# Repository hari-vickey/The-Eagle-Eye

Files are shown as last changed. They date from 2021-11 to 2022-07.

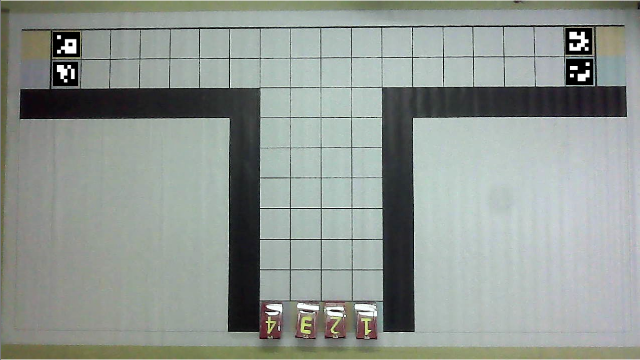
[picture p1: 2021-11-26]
test_programs/images/test.png

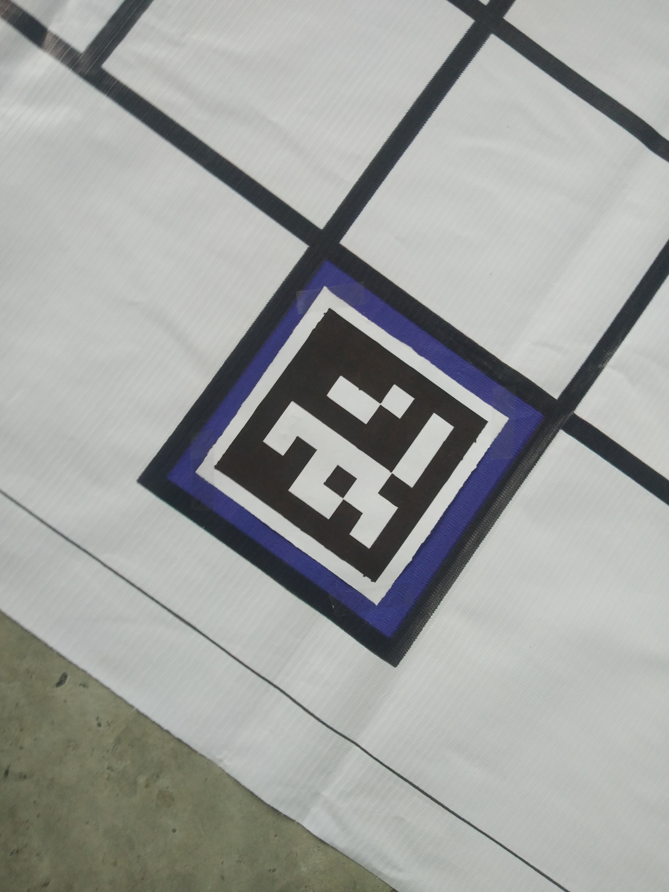
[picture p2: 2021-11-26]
test_programs/images/t.jpg

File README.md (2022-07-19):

# Flipkart GRiD 3.0

<p align="justify">
The Flipkart GRiD 3.0 Robotics Challenge is all set to test the students on their technical, analytical, and ideation skills before they present their unique solutions to the panel of domain experts at Flipkart. The Flipkart GRiD 3.0 Robotics Challenge will assess your skills in the field of analytics and robotics.
</p>

## Problem Statement

<p align="justify">
Behind the scenes in the e-commerce industry lies a sophisticated system of automation and robotics to help bring down costs and deliver goods to customers at the fastest speeds possible. Flipkart's current upcoming facility - expected to be one of the largest in Asia, has a throughput of over 40,000 units/hour. They are constantly looking for ways to increase our scale and speed while trying to minimize cost.
</p>

1. A central monitoring/navigation system (such as a camera or multiple cameras) should be used to understand the arena and the position of the robots and instruct robots on actions to be taken.
2. Swarm algorithms for maximizing the throughput of the given systems.

## The Eagle Eye

<p align="justify">
For the given problem statement, we have designed a central monitoring system based on ROS. The developed system can determine the position of the bot using the camera mounted on the top. Then, the A* algorithm is applied to determine the shortest path for traversal. The communication between the bot and ROS is seamlessly carried out using the ROS socket server. Once the bot reaches the destination, packages are deposited using the servo motor mounted inside the bot.
</p>

<p align="justify">
Our Team Comprises of team members from various engineering domains to formulate the solution for the given problem statement. This repository has all the codes that are being developed, deployed, and validated. So, that the team can share their work easily and update themselves.
</p>

<p align="justify">
We have tried our best to get to the Finals of the competition but we have ended up in completing all the stages(1 & 2) of the competition.
</p>

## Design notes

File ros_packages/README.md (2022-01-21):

# The_Eagle_Eye
## ros_packages

This folder contains multiple ROS packages which are used as the essential blocks for `building` the central monitoring system. To build this package use the below mentioned commands.

```bash
# Build and Source the Package
cd ~/ros_workspace/
catkin build # Repeat build if failed
source devel/setup.bash
# If you have sublime text
subl ~/.bashrc
# else if you have gedit
gedit ~/.bashrc
# Add your workspace to the bashrc file
source ~/ros_workspace/devel/setup.bash
```

## 1. SwarmRobot

This is the ultimate ROS Package which will be acting as the central monitoring system for the problem statement. This package contains various files for controlling the bot in bot simulation and real time applications. Also, this package is capable of interfacing all other packages to do the job.

The commands used to test the files is mentioned below in separate terminals or terminator

```bash
# Launch Camera Node and Socket Server for Bots
roslaunch swarmrobot task.launch
# Run the Aruco Detect Marker and Launch the pyqt5 Application
rosrun swarmrobot pyqt5.py
# Run Client Node
rosrun swarmrobot client.py
# Run Bot'n' Node 'n' ~ 1<=n<=4
# Note : Only Two Bots [2, 4] are used for Stage 2
rosrun swarmrobot bot'n'.py
```

## 2. usb_cam

This package is used to interface the USB camera connected to the USB port of the laptop to ROS Image message at 1280*720p resolution at 30fps. Install the required Modules

```bash
sudo apt-get install v4l-utils
sudo apt-get install ros-<ROS_Distro>-libuvc-camera
```

The camera needed to be configured appropriate to the arena and make sure to add the camera product id and vendor id in the udev.rules in your system as write mode. Refer the below mentioned tutorial

https://msadowski.github.io/ros-web-tutorial-pt2-cameras/

http://wiki.ros.org/libuvc_camera

## 3.  rosserial

This Open Source package is used mainly for ROS and ESP socket communication. The one way communication of the bot and pc takes place with the IP address mentioned in the bot. Make sure to connect the bot and pc with same Wireless credentials.

```bash
# Command to get the IP of desired Wifi Address.
hostname -I
```

## 4. Bot Description

This package contains all the definition of the bot that is being developed in the fusion 360 in xacro format which is in turn converted using fusion2urdf plugin. This package is mainly used for simulation purposes.

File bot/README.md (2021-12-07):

# The_Eagle_Eye
## Bot Programs

This folder contains all the codes for each individual bot which can be utilized for testing purposes and also to be utilized in the ros programs for autonomous navigation.

Each Bot consist of the following Components integrated with it for successful navigation and package delivery. The Circuit diagram will be added soon.

### Components In the Bot

1. NodeMCU V1.0
2. 7805 Voltage Regulator
3. MPU6050 Gyroscopic sensor
4. Servo Motor
5. L298n Motor Driver
6. L shaped BO Motor
7. Li-ion(11V, 2600/2200maH) Battery

## Working 

**NodeMCU** acts as a processing unit for all the bots which is utilized to connect the bot to the ROS server running on the remote PC. So, that the bot can receive commands from them and converts them to digital signal to move the bot and actuate the servo motor.

The **7805 Voltage Regulator** is used to covert 11V input to 5V output which is then provided as input to the NodeMCU, MPU6050, servo motor.

**MPU6050** sensor used to make the bot move precisely in any direction and also to take accurate rotation for any given degree from the server.

**Servo Motor** will act as the barrier to the package from falling from the bot along with the guide ways attached to the bot. Also, by default the servo will be raised up for preventing the package to fall from the bot and rotates 180 degree to make the package fall from the bot.

**L298n Motor Driver** is used mainly to control the direction of the rotation of the motors. But, this component also used for controlling motor speed. As we have utilized the speed control for precise movements.

**L Shaped BO Motor** is used to reduce the actual shaft output speed of the 5V DC Motor to 100 rpm for our application. Also, we have chosen this motor because it's offer to compactable length.

The **Li-ion** Battery is made of three individual Li-ion Cells of 3.7V 2600/2200maH Capacity. The main advantage of this battery is the capability of them to offer current and recharging facility.

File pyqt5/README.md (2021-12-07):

# The_Eagle_Eye
## Pyqt5 Interface

This Folder contains the code of the pyqt5 interface to control the entire central monitoring system. This HMI is mainly created to provide the overall progress of the warehouse. As stated above, we have displayed the information of the current status of each package and bot in real time. Also, the path of each bot that it is tracing.

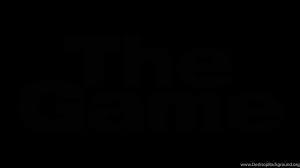
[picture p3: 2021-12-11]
pyqt5/images/black.jpg

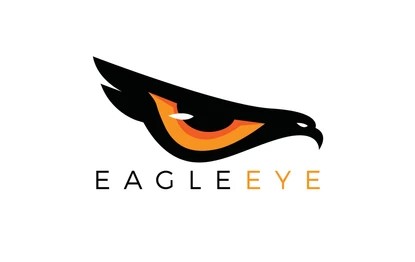
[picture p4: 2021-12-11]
pyqt5/images/eagle_eye.jpg

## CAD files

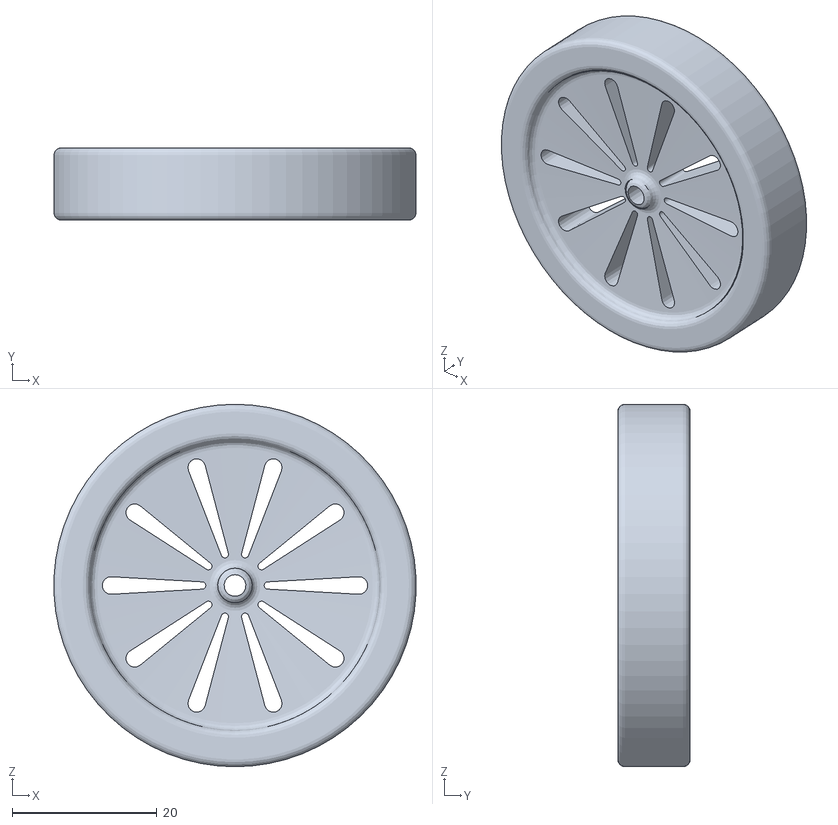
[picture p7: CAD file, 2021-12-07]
ros_packages/bot_description/grid_bot_1_description/meshes/right_wheel_1.stl
49.9 x 10.00 x 50.0

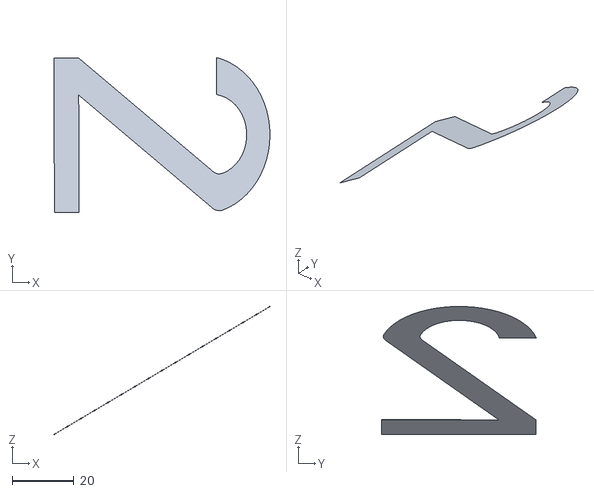
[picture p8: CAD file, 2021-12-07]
ros_packages/bot_description/grid_bot_2_description/meshes/identifier_1.stl
70.0 x 50.2 x 41.5

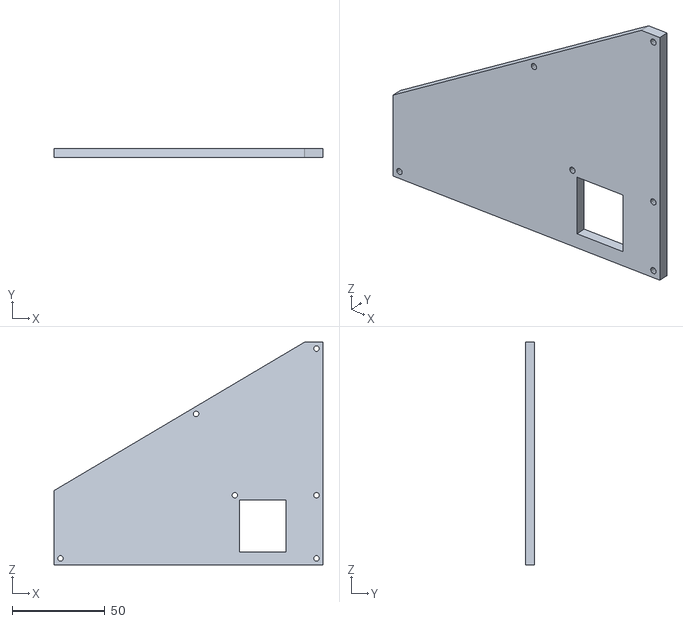
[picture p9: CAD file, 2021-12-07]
ros_packages/bot_description/grid_bot_3_description/meshes/side_pane_1.stl
145.0 x 5.00 x 120.0

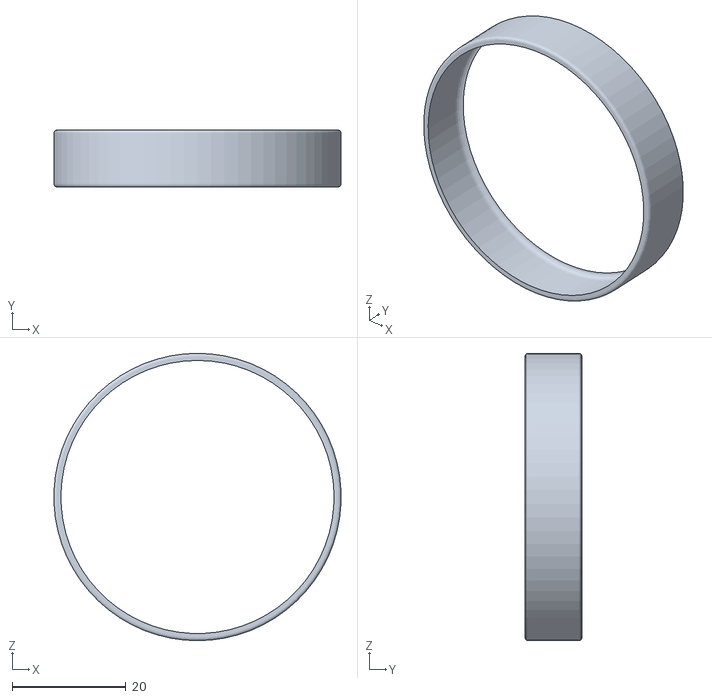
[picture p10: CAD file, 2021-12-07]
ros_packages/bot_description/grid_bot_4_description/meshes/left_wheel_tyre_1.stl
50.4 x 10.0 x 50.5

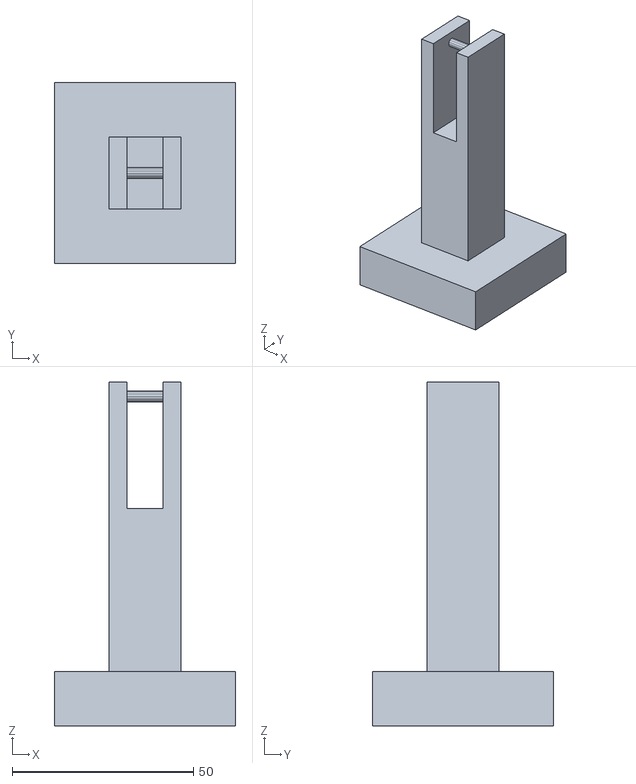
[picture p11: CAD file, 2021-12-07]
ros_packages/check_description/meshes/base_link.stl
50.0 x 50.0 x 95.0

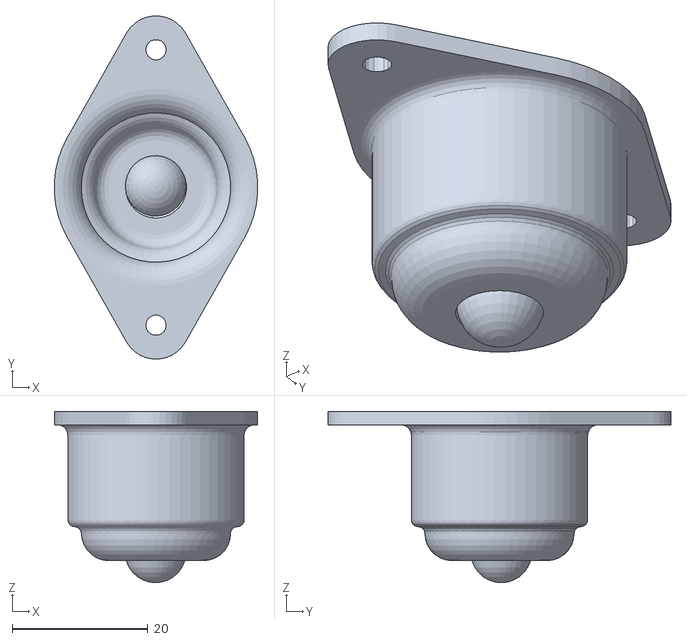
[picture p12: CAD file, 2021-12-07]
ros_packages/grid_bot_description/meshes/castor_wheel_1.stl
30.0 x 50.5 x 25.2

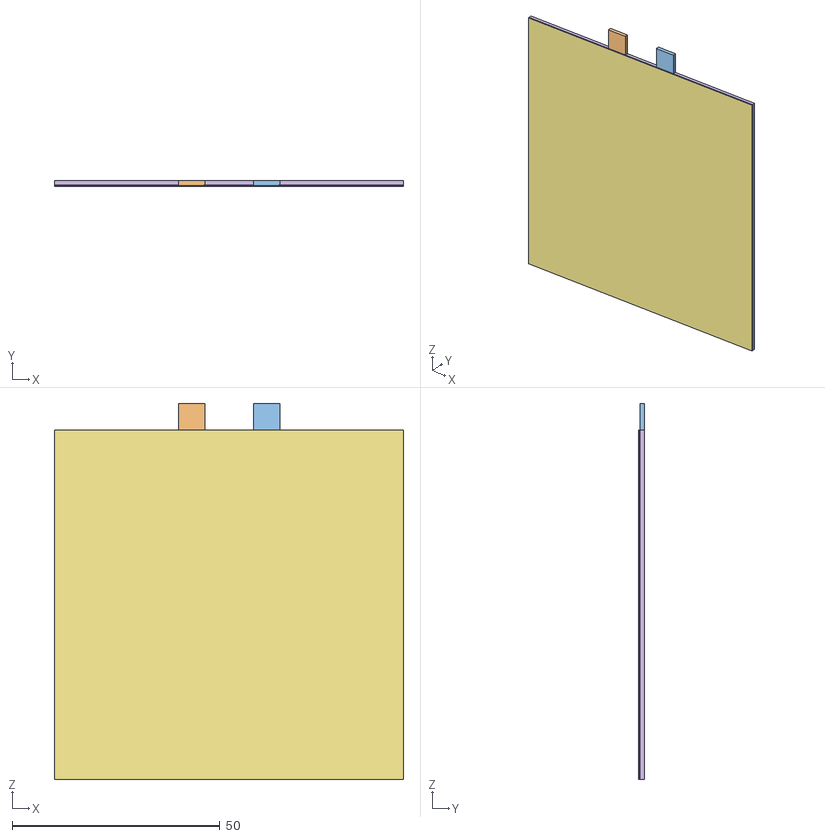
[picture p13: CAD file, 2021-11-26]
ros_packages/swarmrobot/models/arena_s2/meshes/Stage2.obj
84.0 x 1.36 x 90.4
Mesh1 Group2 Component_3_1 Group1 arena1 Model
Mesh2 Group3 Component_3_1 Group1 arena1 Model
Mesh3 Group4 Component_3_1 Group1 arena1 Model
Mesh4 Group5 Component_3_1 Group1 arena1 Model
Mesh5 Group6 Component_3_1 Group1 arena1 Model
Mesh6 Group7 Component_3_1 Group1 arena1 Model
Mesh7 Group8 Component_3_1 Group1 arena1 Model
Mesh8 Group9 Component_3_1 Group1 arena1 Model
Mesh9 Group10 Component_3_1 Group1 arena1 Model
Mesh10 Component_2_1 Component_3_1 Group1 arena1 Model
Mesh11 Component_2_2 Component_3_1 Group1 arena1 Model
Mesh12 Component_3_1 Group1 arena1 Model
Mesh13 Component_3_1 Group1 arena1 Model
Mesh14 Component_3_1 Group1 arena1 Model
Mesh15 Component_3_1 Group1 arena1 Model
Mesh16 Component_3_1 Group1 arena1 Model
Mesh17 Component_3_1 Group1 arena1 Model
Mesh18 Component_3_1 Group1 arena1 Model
Mesh19 Component_3_1 Group1 arena1 Model
Mesh20 Component_3_1 Group1 arena1 Model
Mesh21 Component_3_1 Group1 arena1 Model
Mesh22 Group1 arena1 Model
Mesh23 Group1 arena1 Model
Mesh24 arena1 Model
Mesh25 arena1 Model
Mesh26 arena1 Model
Mesh27 arena1 Model
Mesh28 arena1 Model
Mesh29 arena1 Model
Mesh30 arena1 Model
Mesh31 arena1 Model
Mesh32 arena1 Model

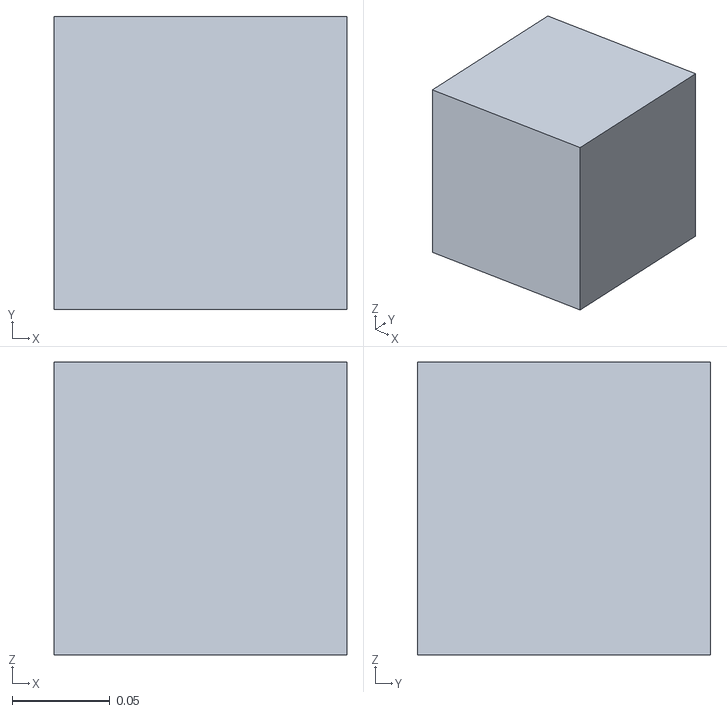
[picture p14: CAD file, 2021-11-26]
ros_packages/swarmrobot/models/green_package/meshes/visual/green_pkg.obj
0.15 x 0.15 x 0.15
Cube_Cube.001
Plane

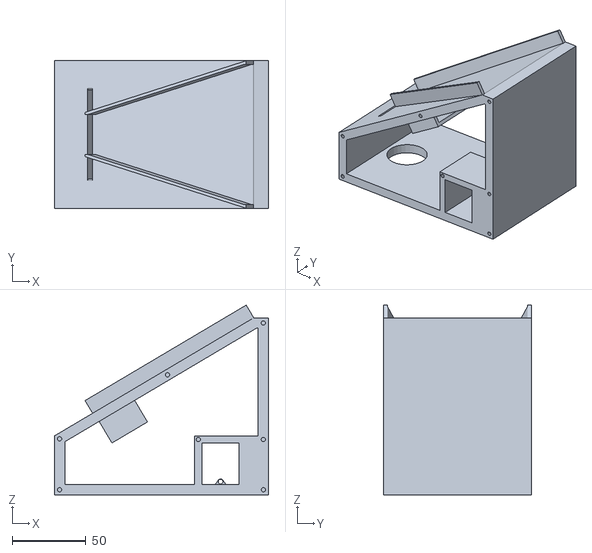
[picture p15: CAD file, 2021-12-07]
ros_packages/bot_description/grid_bot_3_description/meshes/base_link.stl
145.0 x 100.0 x 128.6

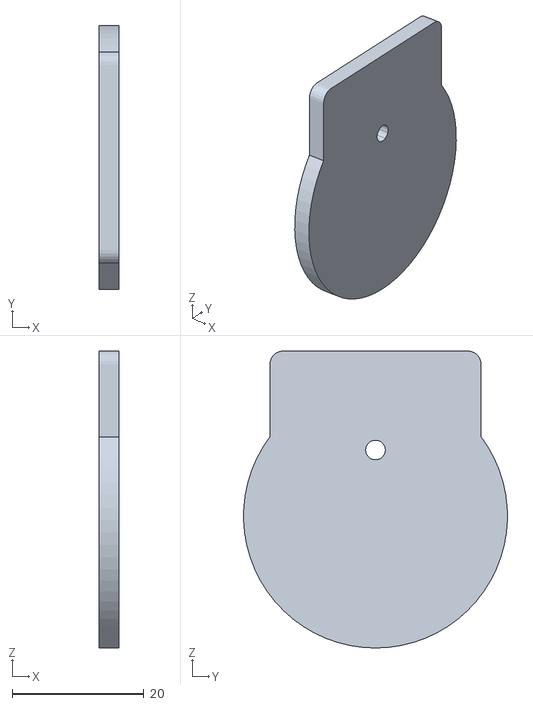
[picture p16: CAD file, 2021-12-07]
ros_packages/check_description/meshes/servo_actuator_1.stl
3.00 x 40.0 x 45.0

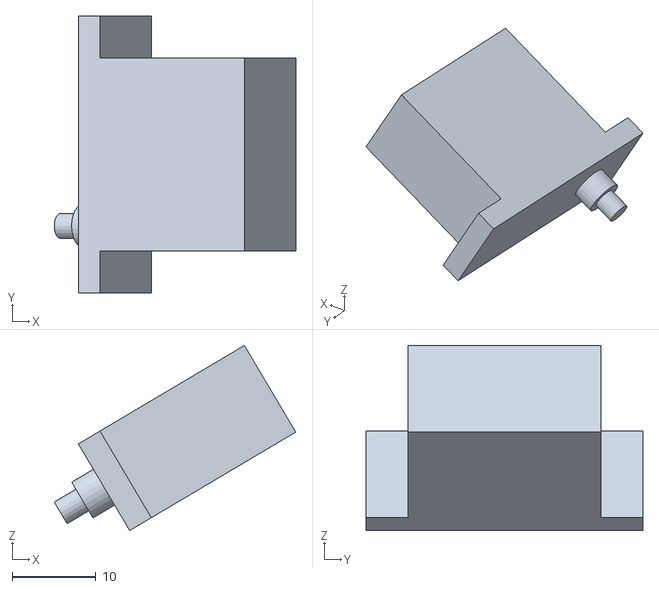
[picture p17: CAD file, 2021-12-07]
ros_packages/grid_bot_description/meshes/servo_motor_1.stl
28.8 x 33.0 x 22.0

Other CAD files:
ros_packages/bot_description/grid_bot_1_description/meshes/right_wheel_tyre_1.stl
ros_packages/bot_description/grid_bot_3_description/meshes/left_wheel_1.stl
ros_packages/bot_description/grid_bot_1_description/meshes/connector_rod_1.stl
ros_packages/bot_description/grid_bot_1_description/meshes/identifier_1.stl
ros_packages/bot_description/grid_bot_1_description/meshes/left_wheel_1.stl
ros_packages/bot_description/grid_bot_1_description/meshes/servo_actuator_1.stl
ros_packages/bot_description/grid_bot_1_description/meshes/side_pane_2.stl
ros_packages/bot_description/grid_bot_2_description/meshes/connector_rod_1.stl
ros_packages/bot_description/grid_bot_2_description/meshes/left_wheel_1.stl
ros_packages/bot_description/grid_bot_2_description/meshes/right_wheel_tyre_1.stl
ros_packages/bot_description/grid_bot_2_description/meshes/servo_actuator_1.stl
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

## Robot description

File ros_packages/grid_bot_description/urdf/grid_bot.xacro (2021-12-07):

<?xml version="1.0" ?>
<robot name="grid_bot" xmlns:xacro="http://www.ros.org/wiki/xacro">

<xacro:include filename="$(find grid_bot_description)/urdf/materials.xacro" />
<xacro:include filename="$(find grid_bot_description)/urdf/grid_bot.trans" />
<xacro:include filename="$(find grid_bot_description)/urdf/grid_bot.gazebo" />
<link name="base_link">
  <inertial>
    <origin rpy="0 0 0" xyz="0.03058315894785165 0.0024807572051702784 0.007996607847452852"/>
    <mass value="3.211035084139386"/>
    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
  </inertial>
  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
</link>

<link name="servo_motor_1">
  <inertial>
    <origin rpy="0 0 0" xyz="0.010587734438734408 0.0084001186327211 0.006274355737184533"/>
    <mass value="0.05328666830943237"/>
    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
  </inertial>
  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
</link>

<link name="servo_actuator_1">
  <inertial>
    <origin rpy="0 0 0" xyz="0.004722447291877676 4.322909012226782e-07 -0.005026760619318817"/>
    <mass value="0.03497018571649247"/>
    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
  </inertial>
  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
</link>

<link name="side_pane_2">
  <inertial>
    <origin rpy="0 0 0" xyz="-0.05195651370572106 -0.0024995677090985935 -0.06871232084610449"/>
    <mass value="0.488960348592679"/>
    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
  </inertial>
  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
</link>

<link name="side_pane_1">
  <inertial>
    <origin rpy="0 0 0" xyz="-0.05195651370572118 0.0025004322909012305 -0.06871232084610446"/>
    <mass value="0.488960348592679"/>
    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
  </inertial>
  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
</link>

<link name="connector_rod_1">
  <inertial>
    <origin rpy="0 0 0" xyz="3.890800441760933e-07 -0.06749956770909944 -2.161915329777775e-07"/>
    <mass value="0.007490931332944163"/>
    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
  </inertial>
  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
</link>

<link name="left_wheel_1">
  <inertial>
    <origin rpy="0 0 0" xyz="3.8680151746156577e-07 0.0042454206608824735 -2.2070271555110765e-07"/>
    <mass value="0.10624530732840641"/>
    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
  </inertial>
  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
</link>

<link name="right_wheel_1">
  <inertial>
    <origin rpy="0 0 0" xyz="3.8680151760034365e-07 -0.004244554213330684 -2.2070271556498544e-07"/>
    <mass value="0.10624530732840641"/>
    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
  </inertial>
  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
</link>

<link name="castor_wheel_1">
  <inertial>
    <origin rpy="0 0 0" xyz="-4.60694217933183e-06 1.876423122246793e-05 -0.007087258397097118"/>
    <mass value="0.036526757425163855"/>
    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
  </inertial>
  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
</link>

<link name="left_wheel_tyre_1">
  <inertial>
    <origin rpy="0 0 0" xyz="3.890801221415052e-07 0.005000419728007896 -2.1619153321023044e-07"/>
    <mass value="0.003489570869816107"/>
    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
  </inertial>
  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
</link>

<link name="right_wheel_tyre_1">
  <inertial>
    <origin rpy="0 0 0" xyz="3.890801222733442e-07 0.005000444853794736 -2.1619153322410822e-07"/>
    <mass value="0.003489570869816107"/>
    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
  </inertial>
  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
</link>

<link name="identifier_1">
  <inertial>
    <origin rpy="0 0 0" xyz="-0.035722546362137245 0.0068016973274355515 -0.020595866570633573"/>
    <mass value="0.0006372800256449409"/>
    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
  </inertial>
  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
</link>

<joint name="servo_fix" type="fixed">
  <origin rpy="0 0 0" xyz="-0.031681 0.002315 0.005433"/>
  <parent link="base_link"/>
  <child link="servo_motor_1"/>
</joint>

<joint name="servo_joint" type="revolute">
  <origin rpy="0 0 0" xyz="-0.003871 0.0 -0.002294"/>
  <parent link="servo_motor_1"/>
  <child link="servo_actuator_1"/>
  <axis xyz="0.860292 0.0 0.509802"/>
  <limit effort="100" lower="0.0" upper="3.141593" velocity="100"/>
</joint>

<joint name="left_pane_fix" type="fixed">
  <origin rpy="0 0 0" xyz="0.075503 -0.047685 0.079034"/>
  <parent link="base_link"/>
  <child link="side_pane_2"/>
</joint>

<joint name="right_pane_fix" type="fixed">
  <origin rpy="0 0 0" xyz="0.075503 0.052315 0.079034"/>
  <parent link="base_link"/>
  <child link="side_pane_1"/>
</joint>

<joint name="connector_fix" type="fixed">
  <origin rpy="0 0 0" xyz="0.046539 0.069315 -0.028466"/>
  <parent link="base_link"/>
  <child link="connector_rod_1"/>
</joint>

<joint name="left_wheel_joint" type="continuous">
  <origin rpy="0 0 0" xyz="0.0 -0.135 0.0"/>
  <parent link="connector_rod_1"/>
  <child link="left_wheel_1"/>
  <axis xyz="-0.0 -1.0 -0.0"/>
</joint>

<joint name="right_wheel_joint" type="continuous">
  <origin rpy="0 0 0" xyz="0.0 0.0 0.0"/>
  <parent link="connector_rod_1"/>
  <child link="right_wheel_1"/>
  <axis xyz="0.0 -1.0 -0.0"/>
</joint>

<joint name="castor_joint" type="fixed">
  <origin rpy="0 0 0" xyz="-0.040997 0.002315 -0.031466"/>
  <parent link="base_link"/>
  <child link="castor_wheel_1"/>
</joint>

<joint name="left_tyre_fix" type="fixed">
  <origin rpy="0 0 0" xyz="0.0 -0.000755 0.0"/>
  <parent link="left_wheel_1"/>
  <child link="left_wheel_tyre_1"/>
</joint>

<joint name="right_tyre_fix" type="fixed">
  <origin rpy="0 0 0" xyz="0.0 -0.009245 0.0"/>
  <parent link="right_wheel_1"/>
  <child link="right_wheel_tyre_1"/>
</joint>

<joint name="identifier_fix" type="fixed">
  <origin rpy="0 0 0" xyz="0.069003 -0.005185 0.082534"/>
  <parent link="base_link"/>
  <child link="identifier_1"/>
</joint>

</robot>

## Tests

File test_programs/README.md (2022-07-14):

# The_Eagle_Eye
## test_programs

This folder contains all the test codes which are being utilized to develop the main code. This codes can be utilized in non-ROS systems for verification and development.

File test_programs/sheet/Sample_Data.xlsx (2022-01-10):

Shipment | Induct Station | Destination
FKMP0001 | 1 | Ahmedabad
FKMP0002 | 1 | Pune
FKMP0006 | 1 | Mumbai
FKMP0011 | 1 | Delhi
FKMP0013 | 1 | Jaipur
FKMP0014 | 1 | Mumbai
FKMP0016 | 1 | Kolkata
FKMP0017 | 1 | Bengaluru
FKMP0020 | 1 | Kolkata
FKMP0021 | 1 | Delhi
FKMP0022 | 1 | Jaipur
FKMP0024 | 1 | Delhi
FKMP0028 | 1 | Chennai
FKMP0035 | 1 | Hyderabad
FKMP0036 | 1 | Delhi
FKMP0039 | 1 | Kolkata
FKMP0040 | 1 | Kolkata
FKMP0041 | 1 | Kolkata
FKMP0043 | 1 | Delhi
FKMP0047 | 1 | Hyderabad
FKMP0048 | 1 | Bengaluru
FKMP0050 | 1 | Jaipur
FKMP0051 | 1 | Delhi
FKMP0053 | 1 | Ahmedabad
FKMP0054 | 1 | Delhi
FKMP0058 | 1 | Chennai
FKMP0061 | 1 | Jaipur
FKMP0062 | 1 | Pune
FKMP0063 | 1 | Chennai
FKMP0064 | 1 | Delhi
FKMP0068 | 1 | Mumbai
FKMP0076 | 1 | Jaipur
FKMP0078 | 1 | Hyderabad
FKMP0079 | 1 | Kolkata
FKMP0083 | 1 | Jaipur
FKMP0090 | 1 | Chennai
FKMP0091 | 1 | Chennai
FKMP0094 | 1 | Delhi
FKMP0096 | 1 | Kolkata
FKMP0097 | 1 | Pune
FKMP0098 | 1 | Ahmedabad
FKMP0099 | 1 | Delhi
FKMP0100 | 1 | Kolkata
FKMP0101 | 1 | Ahmedabad
FKMP0102 | 1 | Jaipur
FKMP0106 | 1 | Jaipur
FKMP0108 | 1 | Jaipur
FKMP0110 | 1 | Delhi
FKMP0111 | 1 | Kolkata
FKMP0112 | 1 | Ahmedabad
FKMP0113 | 1 | Bengaluru
FKMP0116 | 1 | Mumbai
FKMP0119 | 1 | Chennai
FKMP0120 | 1 | Bengaluru
FKMP0121 | 1 | Bengaluru
FKMP0122 | 1 | Delhi
FKMP0123 | 1 | Kolkata
FKMP0127 | 1 | Ahmedabad
FKMP0129 | 1 | Hyderabad
FKMP0130 | 1 | Delhi
FKMP0131 | 1 | Mumbai
FKMP0135 | 1 | Hyderabad
FKMP0136 | 1 | Bengaluru
FKMP0137 | 1 | Bengaluru
FKMP0138 | 1 | Pune
FKMP0140 | 1 | Mumbai
FKMP0141 | 1 | Hyderabad
FKMP0142 | 1 | Chennai
FKMP0144 | 1 | Delhi
FKMP0147 | 1 | Delhi
FKMP0149 | 1 | Delhi
FKMP0151 | 1 | Pune
FKMP0152 | 1 | Hyderabad
FKMP0154 | 1 | Kolkata
FKMP0158 | 1 | Delhi
FKMP0159 | 1 | Kolkata
FKMP0162 | 1 | Hyderabad
FKMP0164 | 1 | Chennai
FKMP0165 | 1 | Jaipur
FKMP0166 | 1 | Hyderabad
FKMP0167 | 1 | Pune
FKMP0168 | 1 | Bengaluru
FKMP0169 | 1 | Pune
FKMP0170 | 1 | Hyderabad
FKMP0176 | 1 | Chennai
FKMP0182 | 1 | Ahmedabad
FKMP0183 | 1 | Ahmedabad
FKMP0185 | 1 | Kolkata
FKMP0186 | 1 | Kolkata
FKMP0190 | 1 | Delhi
FKMP0191 | 1 | Mumbai
FKMP0193 | 1 | Ahmedabad
FKMP0200 | 1 | Pune
FKMP0205 | 1 | Ahmedabad
FKMP0207 | 1 | Jaipur
FKMP0212 | 1 | Delhi
FKMP0214 | 1 | Kolkata
FKMP0215 | 1 | Jaipur
FKMP0217 | 1 | Pune
FKMP0220 | 1 | Kolkata
FKMP0225 | 1 | Kolkata
FKMP0226 | 1 | Mumbai
FKMP0227 | 1 | Ahmedabad
FKMP0228 | 1 | Kolkata
FKMP0232 | 1 | Kolkata
FKMP0234 | 1 | Hyderabad
FKMP0235 | 1 | Delhi
FKMP0239 | 1 | Mumbai
FKMP0241 | 1 | Pune
FKMP0242 | 1 | Bengaluru
FKMP0244 | 1 | Mumbai
FKMP0245 | 1 | Delhi
FKMP0246 | 1 | Mumbai
FKMP0248 | 1 | Chennai
FKMP0249 | 1 | Ahmedabad
FKMP0250 | 1 | Chennai
FKMP0252 | 1 | Ahmedabad
FKMP0253 | 1 | Bengaluru
FKMP0255 | 1 | Ahmedabad
FKMP0257 | 1 | Hyderabad
FKMP0260 | 1 | Ahmedabad
FKMP0261 | 1 | Chennai
FKMP0262 | 1 | Delhi
FKMP0263 | 1 | Chennai
FKMP0264 | 1 | Pune
FKMP0265 | 1 | Jaipur
FKMP0267 | 1 | Bengaluru
FKMP0269 | 1 | Ahmedabad
FKMP0270 | 1 | Bengaluru
FKMP0271 | 1 | Bengaluru
FKMP0273 | 1 | Ahmedabad
FKMP0274 | 1 | Mumbai
FKMP0278 | 1 | Pune
FKMP0283 | 1 | Chennai
FKMP0284 | 1 | Chennai
FKMP0287 | 1 | Bengaluru
FKMP0289 | 1 | Bengaluru
FKMP0291 | 1 | Kolkata
FKMP0292 | 1 | Ahmedabad
FKMP0296 | 1 | Delhi
FKMP0300 | 1 | Kolkata
FKMP0003 | 2 | Ahmedabad
FKMP0004 | 2 | Bengaluru
FKMP0005 | 2 | Kolkata
FKMP0007 | 2 | Delhi
FKMP0008 | 2 | Delhi
FKMP0009 | 2 | Bengaluru
FKMP0010 | 2 | Ahmedabad
FKMP0012 | 2 | Chennai
FKMP0015 | 2 | Hyderabad
FKMP0018 | 2 | Chennai
FKMP0019 | 2 | Ahmedabad
FKMP0023 | 2 | Hyderabad
FKMP0025 | 2 | Bengaluru
FKMP0026 | 2 | Bengaluru
FKMP0027 | 2 | Ahmedabad
FKMP0029 | 2 | Bengaluru
FKMP0030 | 2 | Bengaluru
FKMP0031 | 2 | Hyderabad
FKMP0032 | 2 | Chennai
FKMP0033 | 2 | Mumbai
FKMP0034 | 2 | Delhi
FKMP0037 | 2 | Jaipur
FKMP0038 | 2 | Mumbai
FKMP0042 | 2 | Hyderabad
FKMP0044 | 2 | Chennai
FKMP0045 | 2 | Delhi
FKMP0046 | 2 | Ahmedabad
FKMP0049 | 2 | Ahmedabad
FKMP0052 | 2 | Mumbai
FKMP0055 | 2 | Kolkata
FKMP0056 | 2 | Ahmedabad
FKMP0057 | 2 | Kolkata
FKMP0059 | 2 | Hyderabad
FKMP0060 | 2 | Mumbai
FKMP0065 | 2 | Hyderabad
FKMP0066 | 2 | Jaipur
FKMP0067 | 2 | Mumbai
FKMP0069 | 2 | Chennai
FKMP0070 | 2 | Mumbai
FKMP0071 | 2 | Bengaluru
FKMP0072 | 2 | Hyderabad
FKMP0073 | 2 | Pune
FKMP0074 | 2 | Bengaluru
FKMP0075 | 2 | Bengaluru
FKMP0077 | 2 | Pune
FKMP0080 | 2 | Chennai
FKMP0081 | 2 | Hyderabad
FKMP0082 | 2 | Kolkata
FKMP0084 | 2 | Delhi
FKMP0085 | 2 | Delhi
FKMP0086 | 2 | Mumbai
FKMP0087 | 2 | Chennai
FKMP0088 | 2 | Hyderabad
FKMP0089 | 2 | Hyderabad
FKMP0092 | 2 | Chennai
FKMP0093 | 2 | Kolkata
FKMP0095 | 2 | Pune
FKMP0103 | 2 | Mumbai
FKMP0104 | 2 | Chennai
FKMP0105 | 2 | Bengaluru
FKMP0107 | 2 | Pune
FKMP0109 | 2 | Mumbai
FKMP0114 | 2 | Mumbai
FKMP0115 | 2 | Delhi
FKMP0117 | 2 | Kolkata
FKMP0118 | 2 | Delhi
FKMP0124 | 2 | Hyderabad
FKMP0125 | 2 | Mumbai
FKMP0126 | 2 | Chennai
FKMP0128 | 2 | Hyderabad
FKMP0132 | 2 | Ahmedabad
FKMP0133 | 2 | Jaipur
FKMP0134 | 2 | Delhi
FKMP0139 | 2 | Jaipur
FKMP0143 | 2 | Mumbai
FKMP0145 | 2 | Jaipur
FKMP0146 | 2 | Pune
FKMP0148 | 2 | Delhi
FKMP0150 | 2 | Ahmedabad
FKMP0153 | 2 | Jaipur
FKMP0155 | 2 | Jaipur
FKMP0156 | 2 | Ahmedabad
FKMP0157 | 2 | Jaipur
FKMP0160 | 2 | Ahmedabad
FKMP0161 | 2 | Bengaluru
FKMP0163 | 2 | Delhi
FKMP0171 | 2 | Mumbai
FKMP0172 | 2 | Pune
FKMP0173 | 2 | Chennai
FKMP0174 | 2 | Pune
FKMP0175 | 2 | Chennai
FKMP0177 | 2 | Pune
FKMP0178 | 2 | Chennai
FKMP0179 | 2 | Kolkata
FKMP0180 | 2 | Chennai
FKMP0181 | 2 | Bengaluru
FKMP0184 | 2 | Bengaluru
FKMP0187 | 2 | Delhi
FKMP0188 | 2 | Pune
FKMP0189 | 2 | Pune
FKMP0192 | 2 | Delhi
FKMP0194 | 2 | Jaipur
FKMP0195 | 2 | Ahmedabad
FKMP0196 | 2 | Mumbai
FKMP0197 | 2 | Mumbai
FKMP0198 | 2 | Bengaluru
FKMP0199 | 2 | Bengaluru
FKMP0201 | 2 | Jaipur
FKMP0202 | 2 | Bengaluru
FKMP0203 | 2 | Chennai
FKMP0204 | 2 | Delhi
FKMP0206 | 2 | Bengaluru
FKMP0208 | 2 | Pune
FKMP0209 | 2 | Hyderabad
FKMP0210 | 2 | Ahmedabad
FKMP0211 | 2 | Hyderabad
FKMP0213 | 2 | Ahmedabad
FKMP0216 | 2 | Jaipur
FKMP0218 | 2 | Delhi
FKMP0219 | 2 | Kolkata
FKMP0221 | 2 | Mumbai
FKMP0222 | 2 | Bengaluru
FKMP0223 | 2 | Bengaluru
FKMP0224 | 2 | Hyderabad
FKMP0229 | 2 | Jaipur
FKMP0230 | 2 | Delhi
FKMP0231 | 2 | Pune
FKMP0233 | 2 | Chennai
FKMP0236 | 2 | Kolkata
FKMP0237 | 2 | Pune
FKMP0238 | 2 | Pune
FKMP0240 | 2 | Pune
FKMP0243 | 2 | Hyderabad
FKMP0247 | 2 | Chennai
FKMP0251 | 2 | Kolkata
FKMP0254 | 2 | Delhi
FKMP0256 | 2 | Jaipur
FKMP0258 | 2 | Mumbai
FKMP0259 | 2 | Mumbai
FKMP0266 | 2 | Delhi
FKMP0268 | 2 | Chennai
FKMP0272 | 2 | Jaipur
FKMP0275 | 2 | Ahmedabad
FKMP0276 | 2 | Mumbai
FKMP0277 | 2 | Mumbai
FKMP0279 | 2 | Bengaluru
FKMP0280 | 2 | Ahmedabad
FKMP0281 | 2 | Pune
FKMP0282 | 2 | Kolkata
FKMP0285 | 2 | Hyderabad
FKMP0286 | 2 | Bengaluru
FKMP0288 | 2 | Chennai
FKMP0290 | 2 | Bengaluru
FKMP0293 | 2 | Ahmedabad
FKMP0294 | 2 | Bengaluru
FKMP0295 | 2 | Bengaluru
FKMP0297 | 2 | Delhi
FKMP0298 | 2 | Mumbai
FKMP0299 | 2 | Ahmedabad

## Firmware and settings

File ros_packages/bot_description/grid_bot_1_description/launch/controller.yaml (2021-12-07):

grid_bot_1_controller:
  # Publish all joint states -----------------------------------
  joint_state_controller:
    type: joint_state_controller/JointStateController
    publish_rate: 50

  # Position Controllers --------------------------------------
  servo_joint_position_controller:
    type: effort_controllers/JointPositionController
    joint: servo_joint
    pid: {p: 100.0, i: 0.01, d: 10.0}
  left_wheel_joint_position_controller:
    type: effort_controllers/JointPositionController
    joint: left_wheel_joint
    pid: {p: 100.0, i: 0.01, d: 10.0}
  right_wheel_joint_position_controller:
    type: effort_controllers/JointPositionController
    joint: right_wheel_joint
    pid: {p: 100.0, i: 0.01, d: 10.0}

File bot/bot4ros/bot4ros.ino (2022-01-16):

// Bot 4 Esp Program to Control the movement of the bot and the Servo Motor
// Important Note : Esp8266 is by default active low state 
// It means the HIGH State = 0 and LOW  State = 1

#define ROSSERIAL_ARDUINO_TCP

// Declaring the Header Files required for the Program
#include <ESP8266WiFi.h>
#include <MPU6050_tockn.h>
//#include <MobaTools.h>
#include <Servo.h>
#include <Wire.h>

// Including ROS Libraries for Subscribing to the ROS Topics
#include <ros.h>
#include <std_msgs/Int16MultiArray.h>

// Creating Object for Servo and MPU Sensor
MPU6050 mpu6050(Wire);
//MoToServo servo;
Servo servo;

// Declaring wifi credentials
const char* ssid = "hari";
const char* password = "password";

// Setting the rosserial socket server IP address
// Use hostname -I in terminal to get the IP
// Note : Varies for different wifi connection
IPAddress server(192,168,43,246);// Hari

// Set the rosserial socket server port
const uint16_t serverPort = 44181;

// Creating a ROS Node
ros::NodeHandle n4;

// Defining the Pins for Motor Drivers
int ena = D0;
int in1 = D3;
int in2 = D4;
int in3 = D5;
int in4 = D7;
int enb = D8;

// Defining the Pin for Servo Motor Control
int sm = D6;

// Declare Speed Control Values
int l1 = 220;
int r1 = 160;
int l2 = 125;
int r2 = 125;

// Defining Variables
int count = 1;

// Declare Variable to Store the Value of MPU 6050
float z = 0, zg = 0, z_ang = 0, z_cal = 0;

// Function to get the angle from MPU Sensor
float mpu() {
    mpu6050.update();
    z = mpu6050.getAngleZ();
    Serial.println(z);
    return z;
}

// Function to Move the bot in different Directions
int movement(int direction, float angle=0, int pos=0) {
    if (direction == 0) {
        analogWrite(ena, 0);
        analogWrite(enb, 0);
        Serial.println("Stop");
        count = 1;
        return 0;
    }
    else if (direction == 1) {
        if (count == 1) zg = mpu();
        else if (count == 500) count = 1;
        count++;      
        z_ang = mpu();
        digitalWrite(in1, LOW);
        digitalWrite(in2, HIGH);
        digitalWrite(in3, HIGH);
        digitalWrite(in4, LOW);
        analogWrite(ena, l1);
        analogWrite(enb, r1);
        if(z_ang == zg) {
            analogWrite(ena, l1);
            analogWrite(enb, r1);
        }
        else if(z_ang > zg) {
            r2 = r1 - (5*(z_ang - zg));
            analogWrite(ena, l1);
            analogWrite(enb, r2);
        }
        else if(z_ang < zg) {
            l2 = l1 - (5*(z_ang - zg));
            analogWrite(ena, l2);
            analogWrite(enb, r1);
        }
        Serial.println("Forward");
        return 0;
    }
    else if (direction == 2) {
        z_ang = mpu();
        z_cal = (-(angle)+z_ang);
        while(z_ang >= z_cal) {
            z_ang = mpu();
            digitalWrite(in1, LOW);
            digitalWrite(in2, HIGH);
            digitalWrite(in3, LOW);
            digitalWrite(in4, HIGH);
            analogWrite(ena, l2);
            analogWrite(enb, r2);
            Serial.println("Clock-Wise Rotation");
        }
        analogWrite(ena, 0);
        analogWrite(enb, 0);
        Serial.println("Stop");
        count = 1;
        return 0;
    }
    else if (direction == 3) {
        z_ang = mpu();
        z_cal = ((angle)+z_ang);
        while(z_ang <= z_cal) {
            z_ang = mpu();
            digitalWrite(in1, HIGH);
            digitalWrite(in2, LOW);
            digitalWrite(in3, HIGH);
            digitalWrite(in4, LOW);
            analogWrite(ena, l1);
            analogWrite(enb, r1);
            Serial.println("Anti Clock-Wise Rotation");
        }
        analogWrite(ena, 0);
        analogWrite(enb, 0);
        Serial.println("Stop");
        count = 1;
        return 0;
    }
    else if (direction == 4) {
        if (count == 1) zg = mpu();
        else if (count == 500) count = 1;
        count++;
        z_ang = mpu();
        digitalWrite(in1, HIGH);
        digitalWrite(in2, LOW);
        digitalWrite(in3, LOW);
        digitalWrite(in4, HIGH);
        analogWrite(ena, l1);
        analogWrite(enb, r1);
        if(z_ang == zg) {
            analogWrite(ena, l1);
            analogWrite(enb, r1);
        }
        else if(z_ang < zg) {
            r2 = r1 - (5*(z_ang - zg));
            analogWrite(ena, l1);
            analogWrite(enb, r2);
        }
        else if(z_ang > zg) {
            l2 = l1 - (5*(z_ang - zg));
            analogWrite(ena, l2);
            analogWrite(enb, r1);
        }
        Serial.println("Reverse");
        return 0;
    }
    else if (direction == 5) {
        digitalWrite(in1, LOW);
        digitalWrite(in2, HIGH);
        digitalWrite(in3, LOW);
        digitalWrite(in4, HIGH);
        analogWrite(ena, l1);
        analogWrite(enb, r2);
        Serial.println("Clock-Wise Rotation");
        delay(10);
        analogWrite(ena, 0);
        analogWrite(enb, 0);
        Serial.println("Stop");
        count = 1;
        return 0;
    }
    else if (direction == 6) {
        digitalWrite(in1, HIGH);
        digitalWrite(in2, LOW);
        digitalWrite(in3, HIGH);
        digitalWrite(in4, LOW);
        analogWrite(ena, l2);
        analogWrite(enb, r1);
        Serial.println("Anti Clock-Wise Rotation");
        delay(10);
        analogWrite(ena, 0);
        analogWrite(enb, 0);
        Serial.println("Stop");
        count = 1;
        return 0;
    }
    else if (direction == 7) {
        digitalWrite(in1, HIGH);
        digitalWrite(in2, LOW);
        digitalWrite(in3, LOW);
        digitalWrite(in4, HIGH);
        analogWrite(ena, 150);
        analogWrite(enb, r1);
        Serial.println("Clock-Wise Rotation");
        delay(8);
        analogWrite(ena, 0);
        analogWrite(enb, 0);
        Serial.println("Stop");
        count = 1;
        return 0;
    }
    else if (direction == 8) {
        digitalWrite(in1, HIGH);
        digitalWrite(in2, LOW);
        digitalWrite(in3, LOW);
        digitalWrite(in4, HIGH);
        analogWrite(ena, l1);
        analogWrite(enb, 150);
        Serial.println("Anti Clock-Wise Rotation");
        delay(8);
        analogWrite(ena, 0);
        analogWrite(enb, 0);
        Serial.println("Stop");
        count = 1;
        return 0;
    }
    else if (direction == 9) {
        digitalWrite(in1, LOW);
        digitalWrite(in2, HIGH);
        digitalWrite(in3, HIGH);
        digitalWrite(in4, LOW);
        analogWrite(ena, 150);
        analogWrite(enb, r1);
        Serial.println("Clock-Wise Rotation");
        delay(8);
        analogWrite(ena, 0);
        analogWrite(enb, 0);
        Serial.println("Stop");
        count = 1;
        return 0;
    }
    else if (direction == 10) {
        digitalWrite(in1, LOW);
        digitalWrite(in2, HIGH);
        digitalWrite(in3, HIGH);
        digitalWrite(in4, LOW);
        analogWrite(ena, l1);
        analogWrite(enb, 150);
        Serial.println("Anti Clock-Wise Rotation");
        delay(8);
        analogWrite(ena, 0);
        analogWrite(enb, 0);
        Serial.println("Stop");
        count = 1;
        return 0;
    }
}

// Function to control Servo Motor
int servo_control(int pos) {
    servo.attach(sm);
    if (pos == 0) {
        Serial.println("Servo 0");
        servo.write(0);
    }
    if (pos == 1) {
        Serial.println("Servo 180");
        servo.write(180);
    }
    return 0;
}

// Callback function for control signal
void controlCb(const std_msgs::Int16MultiArray& con){
    Serial.println(con.data[0]);
    Serial.println(con.data[1]);
    Serial.println(con.data[2]);
    servo_control(con.data[2]);
    movement(con.data[0], con.data[1]);
}

// Subscribe to the ROS Topic
ros::Subscriber<std_msgs::Int16MultiArray> sub_con("bot4/control_signal", &controlCb);

void setup() {
    // Set Up esp8266 as Output or Input
    pinMode(ena, OUTPUT);
    pinMode(in1, OUTPUT);
    pinMode(in2, OUTPUT);
    pinMode(in3, OUTPUT);
    pinMode(in4, OUTPUT);
    pinMode(enb, OUTPUT);

    // Attach Servo Motor Signal Pin
    servo.attach(sm);

    // On Boot Set Speed Control Pins to zero
    analogWrite(ena, 0);
    analogWrite(enb, 0);
    servo_control(0);

    // Use ESP8266 serial to monitor the process
    // Note: Change your bps at the serial monitor to the below mentioned Value
    Serial.begin(115200);

    // Connect the ESP8266 the the wifi AP
    WiFi.begin(ssid, password);
    while (WiFi.status() != WL_CONNECTED) {
        delay(500);
        Serial.print(".");
    }

    Serial.println("");
    Serial.println("WiFi connected");
    Serial.println("IP address: ");
    Serial.println(WiFi.localIP());

    //Initialize the I2C Communication
    Wire.begin();
    // Initialize the MPU 6050 Sensor
    mpu6050.begin();
    z_cal  = mpu();

    // Set the connection to rosserial socket server
    n4.getHardware()->setConnection(server, serverPort);

    // Initialize ROS Node
    n4.initNode();

    // Subscribing the ROS Topics
    n4.subscribe(sub_con);
}

// Loop the neccessary Functions
void loop() {
    n4.spinOnce();
}

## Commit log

2021-11-26 Swarmrobot Package and Test Program Files Added
    [Sample_Data.xlsx, Stage2.obj, controllers.yaml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]
2021-11-30 Test Case Validated
2021-12-02 Updated to Socket Server for Communication
2021-12-07 Repository Tree Finalized
    [Stage2.obj, controllers.yaml, green_pkg.obj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]
2021-12-07 Files Updated
    [Stage2.obj, aruco_1.stl, base_link.stl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]
2021-12-09 Added Instructions for libuvc camera Installation
2021-12-11 added images for showing in the frame
2021-12-14 Threading Removed
2022-01-07 Updated Servo Library
2022-01-07 Corrected Bot ROS Codes
    [bot1ros.ino, bot2ros.ino, bot3ros.ino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]
2022-01-10 Updated Sample Sheet
    [Sample_Data.xlsx]
2022-01-11 Removed Duplicates
    [Sample_Data.xlsx]
2022-01-11 Pyqt Integrated with ROS Basic Version
    [Sample_Data.xlsx]
2022-01-12 updated pyqt-ros integration
    [Book1.xlsx, Book2.xlsx]
2022-01-12 Path Redefined
    [Book1.xlsx, Book2.xlsx]
2022-01-12 Servo turns 90 only

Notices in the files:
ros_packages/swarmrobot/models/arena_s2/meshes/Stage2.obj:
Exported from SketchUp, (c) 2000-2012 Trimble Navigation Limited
